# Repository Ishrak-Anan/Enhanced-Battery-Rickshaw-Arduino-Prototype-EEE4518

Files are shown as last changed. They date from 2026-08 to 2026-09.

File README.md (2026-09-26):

# Enhanced Battery Rickshaw Arduino Prototype — EEE 4518

An Arduino-based hardware prototype developed to explore practical **safety and energy-efficiency enhancements for battery-powered rickshaws**. The system integrates manual PWM motor control, ultrasonic obstacle detection with automatic stopping, LCD feedback, dual DC-motor control, and solar-assisted auxiliary functionality.

**Course:** EEE 4518  
**Project Type:** Open-ended Real-Life Engineering Problem  
**Team:** Team MurubbEEE

---

## Overview

Battery-powered rickshaws are widely used for short-distance transportation in Bangladesh. However, conventional battery rickshaws often have limited safety features, basic driver feedback, and high dependence on externally charged batteries.

This project explored several engineering modifications through a **physical hardware prototype** controlled by an Arduino.

The final prototype incorporated:

- Arduino-based control
- Driver-controlled PWM motor speed
- Dual DC-motor operation
- Ultrasonic obstacle detection
- Automatic motor stopping
- LCD information display
- Solar-panel integration
- Auxiliary lighting
- Hardware-level implementation and testing

---

## Problem Statement

The project was motivated by several issues associated with conventional battery-powered rickshaws:

- Uncontrolled or excessive speed
- Risk of collision
- Limited safety systems
- High electricity consumption
- Lack of driver information systems
- Limited use of renewable energy sources

The objective was to demonstrate how embedded electronics, sensors, motor control, and renewable-energy concepts could be integrated into a prototype platform.

---

## My Contribution

This project was developed collaboratively as part of our **EEE 4518 — Electrical and Electronic Workshop** coursework at the Islamic University of Technology (IUT).

My contributions included:

- **Component Research & Selection** — Researched and helped identify the components required for the proposed battery-rickshaw enhancement system.
- **Component Procurement** — Participated in sourcing and purchasing the finalized hardware components for the prototype.
- **Hardware Implementation** — Contributed directly to the physical implementation of the prototype, particularly **wiring and soldering**.
- **Hardware Debugging & Troubleshooting** — Worked on identifying and resolving hardware-related issues during prototype development and testing.
- **Presentation Development** — Prepared the complete project presentation, with support from a teammate.

The project was a collaborative team effort, and the original repository is maintained by
[Ar-Rafi-Ishraq](https://github.com/Ar-Rafi-Ishraq/Enhanced-Battery-Rickshaw-Arduino-Prototype-EEE4518).

## Hardware Prototype

<p align="center">
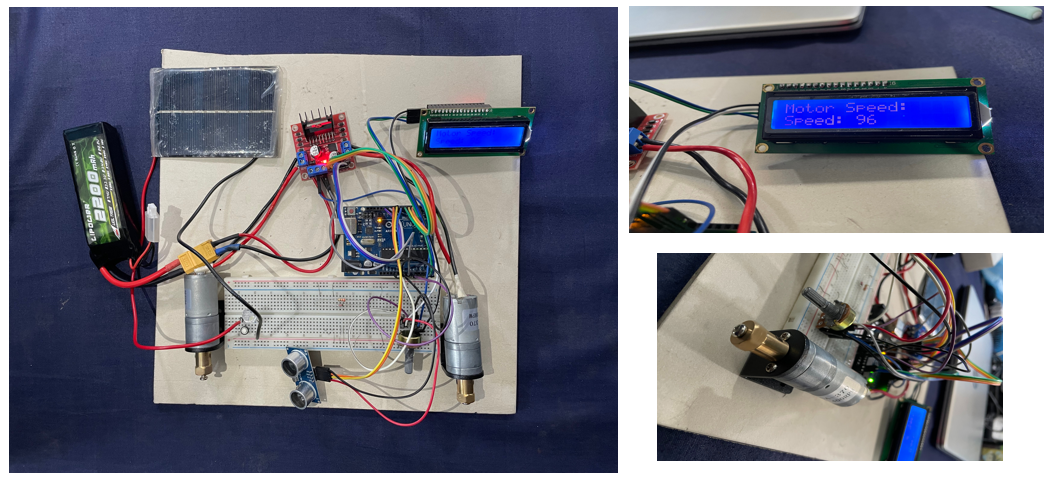
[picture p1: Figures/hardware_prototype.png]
Enhanced Battery Rickshaw Hardware Prototype
  
</p>

The physical prototype integrates the Arduino controller, motor driver, two DC motors, ultrasonic sensor, LCD, potentiometer-based driver input, solar panel, and supporting electronics.

---

## Circuit Schematic

The circuit schematic was designed using **Fritzing**.

<p align="center">
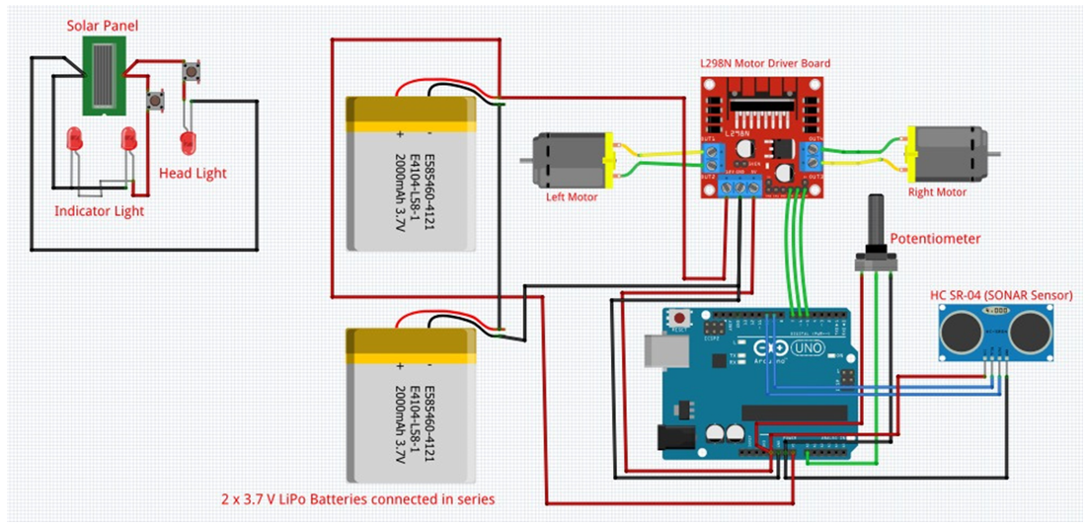
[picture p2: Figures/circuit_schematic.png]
Fritzing Circuit Schematic
  
</p>

The editable Fritzing project is available here:

[`Fritzing/l298n-arduino.fzz`](Fritzing/l298n-arduino.fzz)

---

# Implemented Features

## 1. Manual Motor Speed Control

A potentiometer connected to Arduino analog input `A0` acts as the driver's motor-speed command.

The Arduino reads the analog input and converts it into a PWM command for the L298N motor driver.

The PWM output is limited to:

```text
0 – 178
```

rather than the complete Arduino 8-bit PWM range of `0 – 255`.

Both DC motors receive the corresponding PWM command through the L298N motor driver.

> **Note:** The displayed speed value represents the motor PWM command, not an actual vehicle-speed measurement in km/h.

---

## 2. Obstacle Detection

An **HC-SR04 ultrasonic sensor** is mounted at the front of the prototype to measure the distance to nearby obstacles.

The Arduino continuously calculates the distance using the ultrasonic sensor.

The implemented safety threshold is:

```text
20 cm
```

If an obstacle is detected within approximately 20 cm, the system automatically stops both motors.

---

## 3. Automatic Motor Stopping

The motor-control logic follows:

```text
If distance < 20 cm:
    Stop both motors

Otherwise:
    Run motors according to potentiometer input
```

This provides a basic collision-avoidance mechanism for the prototype.

---

## 4. LCD Information Display

A **16×2 LCD with an I2C adapter** is used to provide information to the driver.

The display shows the motor-speed command generated from the potentiometer input.

I2C communication reduces the number of Arduino pins required for the LCD.

---

## 5. Dual-Motor Drive

Two DC geared motors are driven through an **L298N dual H-bridge motor driver**.

The Arduino controls:

- Motor direction
- Motor enable signals
- PWM speed command

Both motors are configured to move the prototype forward during normal operation.

---

## 6. Solar Integration

A small solar panel was incorporated into the prototype as part of the proposed renewable-energy enhancement.

The prototype demonstrates the concept of using solar energy for auxiliary electrical loads.

It does **not** implement a complete solar battery-charging system or maximum-power-point-tracking controller.

---

# System Control Flow

<p align="center">
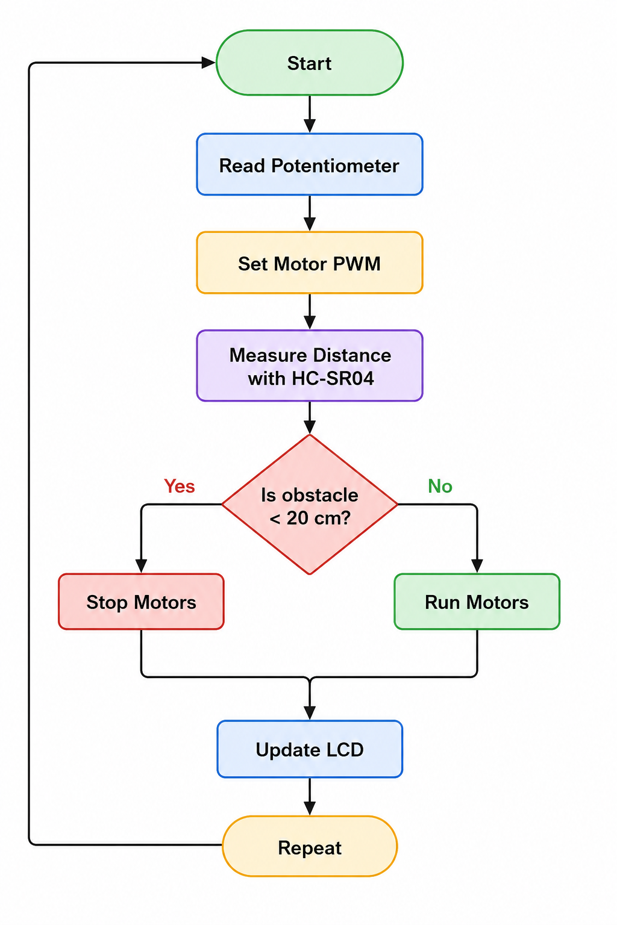
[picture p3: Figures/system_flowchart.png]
Arduino Control System Flowchart
  
</p>

The Arduino control process can be summarized as:

```text
Start
  ↓
Read Potentiometer
  ↓
Set Motor PWM
  ↓
Measure Distance with HC-SR04
  ↓
Is obstacle < 20 cm?
  ├── Yes → Stop Motors
  └── No  → Run Motors
  ↓
Update LCD
  ↓
Repeat
```

---

# Arduino Pin Connections

| Component | Signal | Arduino Pin |
|---|---|---:|
| HC-SR04 | Trigger | 9 |
| HC-SR04 | Echo | 10 |
| L298N Motor A | ENA / PWM | 5 |
| L298N Motor A | IN1 | 6 |
| L298N Motor A | IN2 | 7 |
| L298N Motor B | ENB / PWM | 11 |
| L298N Motor B | IN3 | 8 |
| L298N Motor B | IN4 | 12 |
| Potentiometer | Wiper | A0 |
| I2C LCD | SDA | A4 |
| I2C LCD | SCL | A5 |

A **common ground** is required between the Arduino, L298N, sensors, display, and motor power supply.

Detailed wiring information is available here:

[`Docs/Pin_Connections.docx`](Docs/Pin_Connections.docx)

---

# Arduino Firmware

The main Arduino source code is available at:

[`Arduino/TotalProjectCodeRickshaw.ino`](Arduino/TotalProjectCodeRickshaw.ino)

The firmware performs:

- Analog potentiometer reading
- PWM motor-speed command generation
- Dual-motor control
- Motor-direction control
- HC-SR04 distance measurement
- Obstacle detection
- Automatic motor stopping
- LCD updates
- I2C communication

---

## Required Arduino Libraries

The firmware uses:

```cpp
#include <Wire.h>
#include <LiquidCrystal_I2C.h>
```

`Wire` is included with the Arduino platform.

A compatible **LiquidCrystal_I2C** library must be installed before compiling the project.

---

# How to Run

## 1. Hardware Setup

Connect the components according to:

```text
Docs/Pin_Connections.docx
```

Important connections include:

```text
HC-SR04:
Trig → Pin 9
Echo → Pin 10

Motor A:
ENA → Pin 5
IN1 → Pin 6
IN2 → Pin 7

Motor B:
ENB → Pin 11
IN3 → Pin 8
IN4 → Pin 12

Potentiometer:
Wiper → A0

LCD:
SDA → A4
SCL → A5
```

---

## 2. Upload the Firmware

1. Open **Arduino IDE**.
2. Open:

```text
Arduino/TotalProjectCodeRickshaw.ino
```

3. Install a compatible `LiquidCrystal_I2C` library if necessary.
4. Select the correct Arduino board.
5. Select the correct serial port.
6. Compile the program.
7. Upload it to the Arduino.

---

## 3. Test the System

Rotate the potentiometer to change the motor-speed command.

Move an object in front of the HC-SR04 sensor.

When the measured distance becomes less than approximately:

```text
20 cm
```

both motors should automatically stop.

Remove the obstacle and the motors should resume operation according to the potentiometer input.

---

# Main Hardware Components

The prototype uses the following major components:

| Component | Quantity |
|---|---:|
| Arduino Uno | 1 |
| L298N Dual H-Bridge Motor Driver | 1 |
| HC-SR04 Ultrasonic Sensor | 1 |
| DC Gear Motors | 2 |
| 16×2 LCD | 1 |
| I2C LCD Adapter | 1 |
| Potentiometer | 2 |
| Solar Panel | 1 |
| LiPo Battery / Power Supply | 1 |
| LED / Auxiliary Lighting | 1 |
| Jumper Wires and Connecting Hardware | As required |

The initial component estimate created during project planning is preserved in:

[`Archive/initial_component_budget.txt`](Archive/initial_component_budget.txt)

---

# Project Documentation

The project documentation is available in the [`Docs`](Docs/) directory.

## Final Project Report

[`EEE4518_Final_Project_Report.pdf`](Docs/EEE4518_Final_Project_Report.pdf)

The report documents the completed project, including:

- Problem identification
- Project objectives
- Component selection
- Circuit design
- Working principle
- Arduino implementation
- Hardware implementation
- Problems encountered
- Final prototype
- Conclusion
- References

---

## Project Proposal

[`EEE4518_Project_Proposal.pdf`](Docs/EEE4518_Project_Proposal.pdf)

The original proposal contains the initial project concept and the broader set of enhancements considered during the planning stage.

---

## Pin Connections

Detailed wiring and Arduino pin assignments are available in:

[`Docs/Pin_Connections.docx`](Docs/Pin_Connections.docx)

---

## Progress Updates

Intermediate development documentation is available in:

[`Docs/Progress_Updates/`](Docs/Progress_Updates/)

---

# Presentation

The final project presentation is available in the [`Presentation`](Presentation/) directory.

Files:

- [`Team-MurubbEEE-Final-Presentation.pdf`](Presentation/Team-MurubbEEE-Final-Presentation.pdf)
- [`Team-MurubbEEE-Final-Presentation.pptx`](Presentation/Team-MurubbEEE-Final-Presentation.pptx)

---

# Repository Structure

```text
Enhanced-Battery-Rickshaw-Arduino-Prototype-EEE4518/
│
├── README.md
│
├── Archive/
│   └── initial_component_budget.txt
│
├── Arduino/
│   └── TotalProjectCodeRickshaw.ino
│
├── Docs/
│   ├── Progress_Updates/
│   ├── EEE4518_Final_Project_Report.pdf
│   ├── EEE4518_Project_Proposal.pdf
│   └── Pin_Connections.docx
│
├── Figures/
│   ├── circuit_schematic.png
│   ├── hardware_prototype.png
│   └── system_flowchart.png
│
├── Fritzing/
│   └── l298n-arduino.fzz
│
└── Presentation/
    ├── Team-MurubbEEE-Final-Presentation.pdf
    └── Team-MurubbEEE-Final-Presentation.pptx
```

---

# Project Evolution

The original proposal considered several possible enhancements, including:

- Speed sensing
- Automatic response to overspeeding
- Obstacle detection
- Solar integration
- Reverse/recovery charging
- Lighting
- Driver information display

Not every proposed feature was implemented in the final prototype.

The completed hardware prototype focused on:

- Potentiometer-based motor-speed command
- PWM motor control
- HC-SR04 obstacle detection
- Automatic stopping
- LCD feedback
- Dual-motor control
- Solar-assisted auxiliary integration

Separating the **proposed features** from the **implemented features** provides a more accurate representation of the completed engineering work.

---

# Current Limitations

This prototype was developed as an educational proof of concept and has several limitations:

- No wheel encoder or Hall-effect sensor for actual vehicle-speed measurement
- No calibrated speed measurement in km/h
- LCD displays the PWM control command rather than actual vehicle speed
- No battery state-of-charge monitoring
- No regenerative braking implementation
- No reverse-charging implementation
- No closed-loop motor-speed control
- No production-grade braking actuator
- No complete solar charge controller
- Fixed prototype-scale obstacle threshold
- L298N motor driver is appropriate for the prototype but not for a full-scale rickshaw traction motor

Therefore, this project should be considered a **prototype demonstration**, not a road-ready vehicle control system.

---

# Possible Future Improvements

Future versions of the system could include:

- Wheel-speed sensing using a Hall sensor or encoder
- Calibrated speed measurement in km/h
- Closed-loop speed control
- Speed-dependent stopping distance
- Battery voltage and current monitoring
- Battery state-of-charge estimation
- Dedicated solar charge controller
- Higher-efficiency motor controller
- Regenerative braking
- Indicator and headlight automation
- Data logging
- Wireless telemetry
- Full-scale braking-system integration
- Vehicle-level safety testing

---

# Team

This project was developed by **Team MurubbEEE**:

- Ar-Rafi Ishraq
- Ishrak Anan
- Taufeeq Hassan Omio
- Ashfiq Ul Rahman
- Tahsik Islam Sampad
- Bayzid Mohammed Sakib

---

# Tools and Technologies

- Arduino Uno
- Arduino IDE
- Embedded C/C++
- Fritzing
- Tinkercad during development
- HC-SR04 ultrasonic sensing
- L298N H-bridge motor driver
- PWM motor control
- I2C communication
- 16×2 LCD
- DC motor control
- Hardware prototyping
- Soldering and circuit assembly

---

# Academic Context

This project was completed as an **open-ended engineering project for EEE 4518**.

The objective was to identify a real-world problem and use engineering knowledge to design and implement a practical solution.

The selected problem was the enhancement of battery-powered rickshaws through embedded control, safety sensing, driver feedback, and renewable-energy concepts.

---

# Repository Maintainer

**Ar-Rafi Ishraq**  
Electrical and Electronic Engineering

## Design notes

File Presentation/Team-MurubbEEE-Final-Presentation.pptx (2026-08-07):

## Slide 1

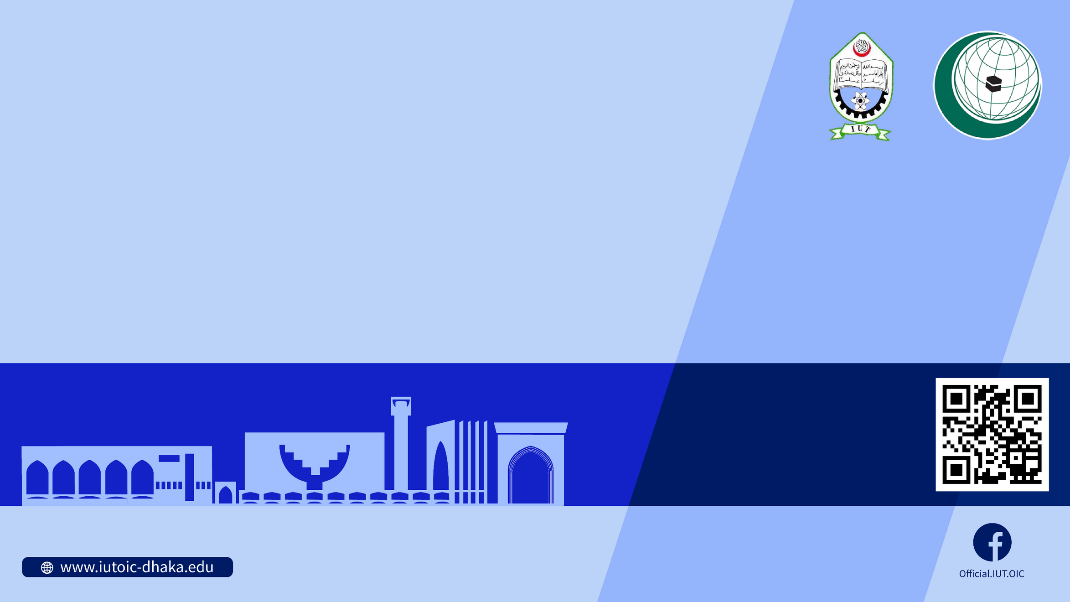
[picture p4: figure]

FINAL PROJECT DEMONESTRATION

EEE 4518: ELECTRICAL AND ELECTRONIC WORKSHOP

PROJECT TITLE: ENHANCEMENT OF BATTERY-POWERED RICKSHAW

Submitted by – Team Murubb_EEE

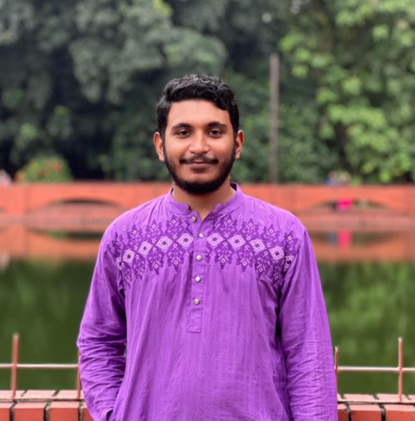
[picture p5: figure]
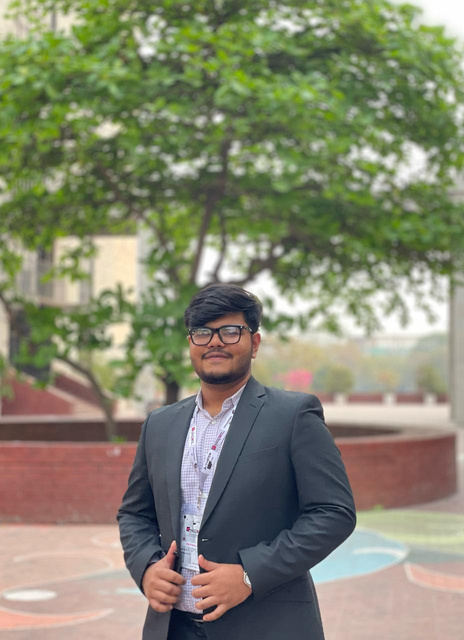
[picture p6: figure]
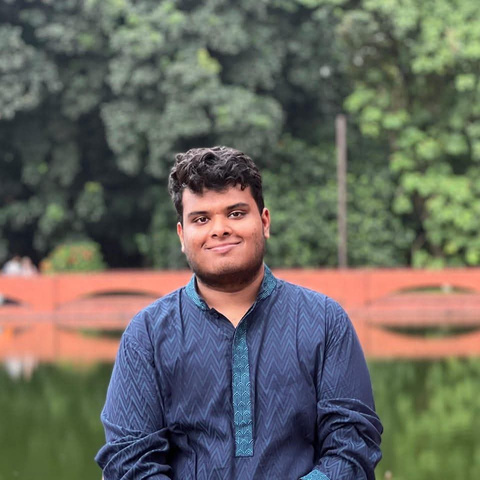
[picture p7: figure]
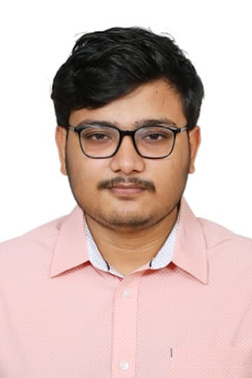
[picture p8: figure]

AR RAFI ISHRAQ
210021330

ISHRAK ANAN
210021212

TAUFEEQ HASSAN OMIO
210021214

ASHFIQ UL RAHMAN
210021342

TAHSIK ISLAM SAMPAD
210021318

BAYZID MOHAMMED SAKIB
210021250

Creating Global Citizens Rooted with Islamic Values

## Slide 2

OUTLINE

  1. ABSTRACT
  2. PROBLEM STATEMENTS AND PROPOSED SOLUTIONS
  3. DESIGN
  4. IMPLEMENTATION
  5. ANALYSIS AND EVOLUTION
  6. REFLECTION OF INDIVIDUAL AND TEAMWORK
  7. REFERENCES

3

2

Creating Global Citizens Rooted with Islamic Values

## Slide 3

We, team Murubbeee, aim to work on enhancing battery-run rickshaws in Bangladesh. Battery rickshaws have become a common urban transportation in Bangladesh, especially in busy cities like Dhaka, and Chittagong. According to Dhaka Tribune’s report on May 24, 2024, almost 60 lakh battery rickshaws are operating on the streets of Bangladesh. These rickshaws provide us with the benefits of fast transportation as compared to their counterpart, human-powered rickshaws. However, these benefits come with a price. Battery rickshaws are the major reasons for accidents, excessive electricity usage, and traffic-related issues. To address these issues and also upgrade these battery-run rickshaws for more efficient results, we propose our newly modified battery rickshaws.

ABSTRACT

3

3

Creating Global Citizens Rooted with Islamic Values

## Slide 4

PROBLEM STATEMENTS

1. Unnecessary speeding of battery rickshaws.
2. Collisions that lead to minor or severe injuries and life threats
3. Excessive use of electricity for charging the battery-run rickshaws
4. Lack of safety measurements in the rickshaws
5. Absence of an information system in the rickshaw.

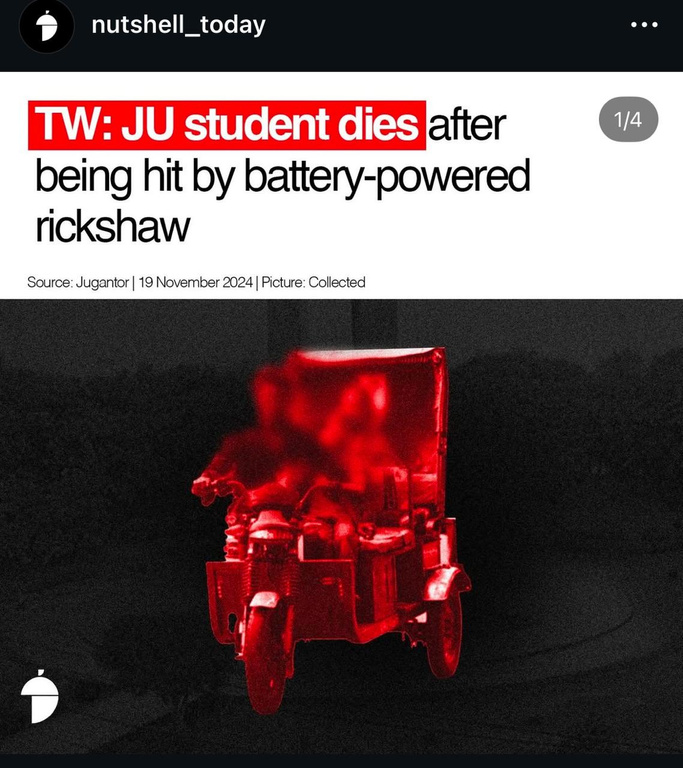
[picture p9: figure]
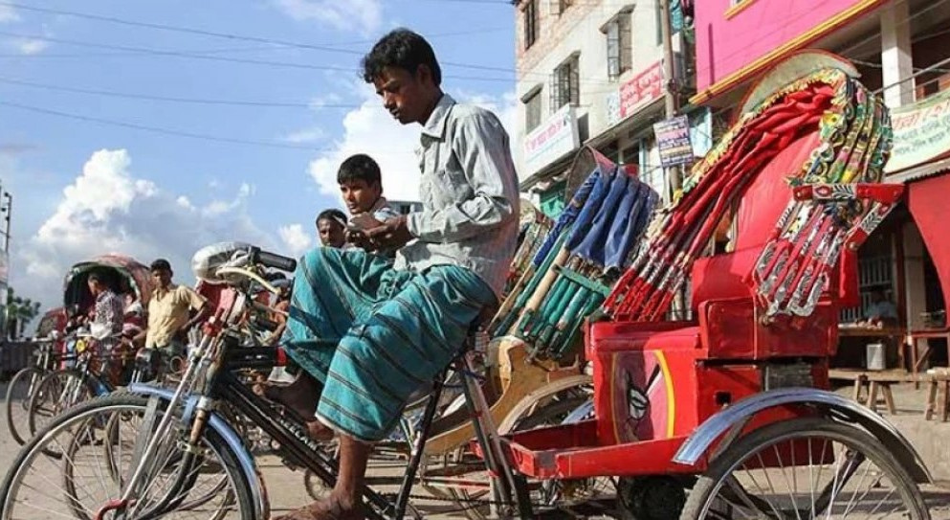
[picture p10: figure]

Creating Global Citizens Rooted with Islamic Values

4

4

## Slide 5

PROPOSED SOLUTIONS

  1. Solar panel installation on the top of rickshaw hoods
  2. Speed sensors to detect the speed of the rickshaw
  3. Obstacle detector to be installed at the front portion
  4. A system that can respond to overspeed and reduce chances of collisions by controlling the power supply to motor.
  5. Addition of indicator lamps and headlamps
  6. Information system (LED display) to show necessary data (speed, charge, etc.)

5

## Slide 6

3.1 DESIGN: METHODS

Components Used in the prototype:
  - ARDUINO
  - 400 RPM motors
  - Dual Motor Drivers
  - Solar Panel
  - Speed Measuring Module
  - LCD Panels
  - SONAR sensor
  - LED indicators

Microcontroller Used: ATmega328

Code implemented by: Arduino IDE

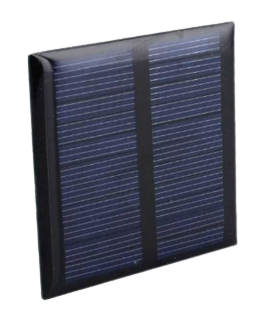
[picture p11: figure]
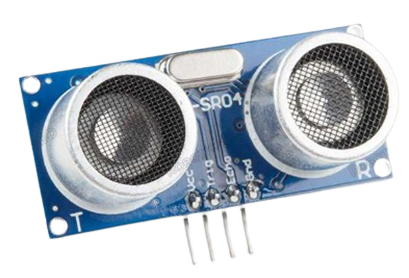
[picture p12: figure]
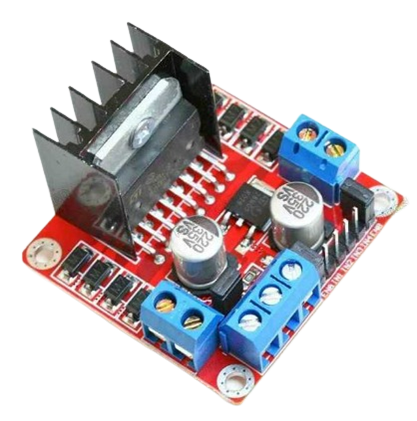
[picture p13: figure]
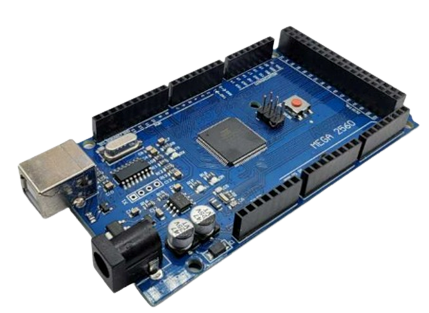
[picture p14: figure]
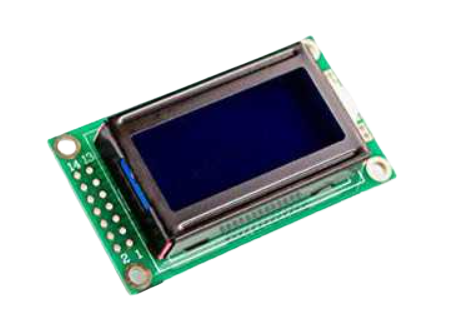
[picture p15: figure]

5

6

Creating Global Citizens Rooted with Islamic Values

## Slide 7

3.2 DESIGN: CIRCUIT DIAGRAM

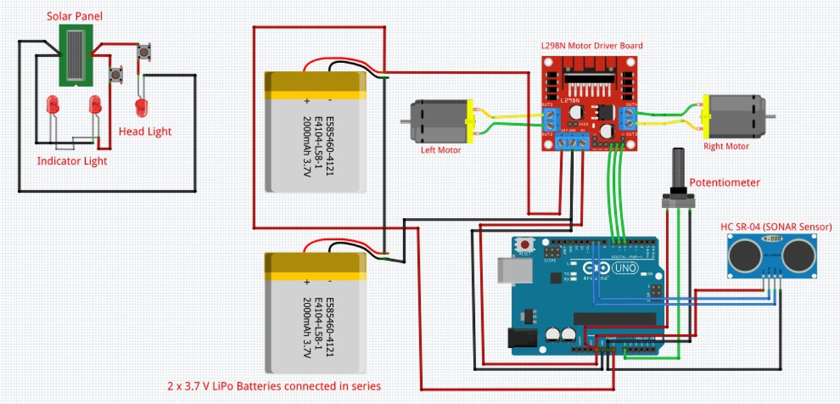
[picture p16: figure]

Creating Global Citizens Rooted with Islamic Values

5

7

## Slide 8

3.3 DESIGN: SIMULATION

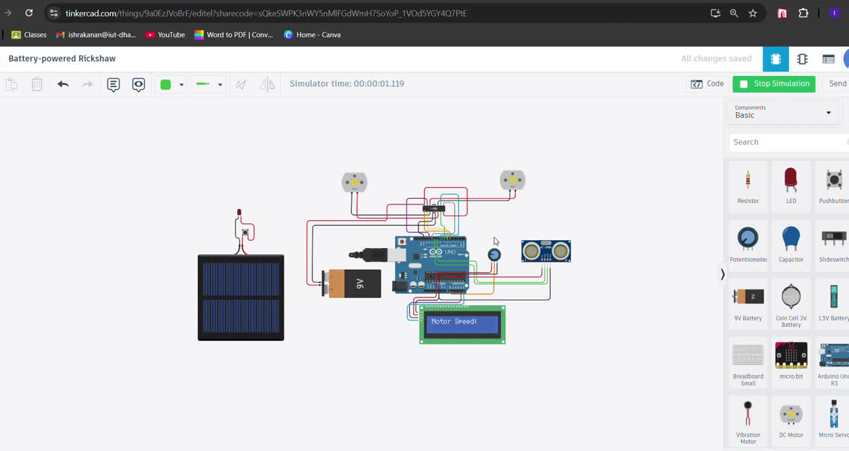
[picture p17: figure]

Creating Global Citizens Rooted with Islamic Values

5

8

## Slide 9

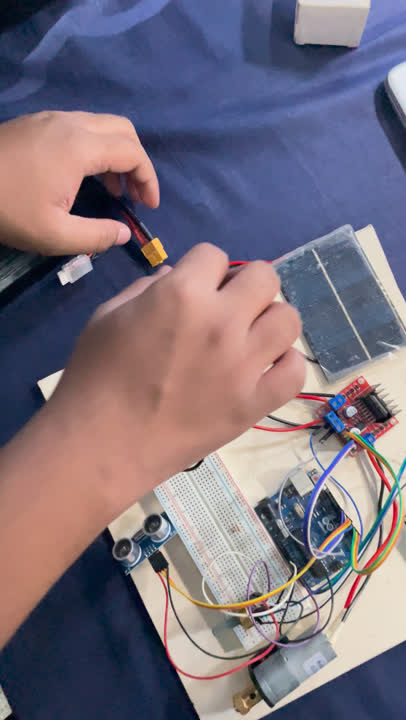
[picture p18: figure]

Creating Global Citizens Rooted with Islamic Values

4. IMPLEMENTATION:
DEMONSTRATION

5

9

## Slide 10

4.1 IMPLEMENTATION: PHOTO GALLERY

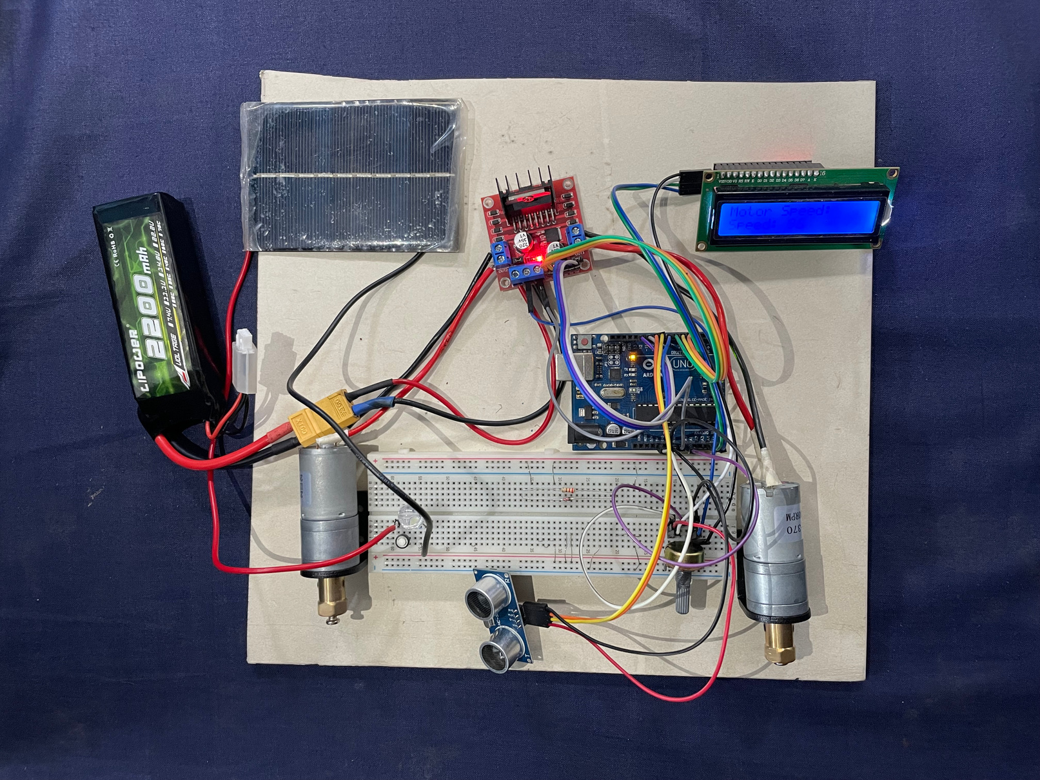
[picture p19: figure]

Creating Global Citizens Rooted with Islamic Values

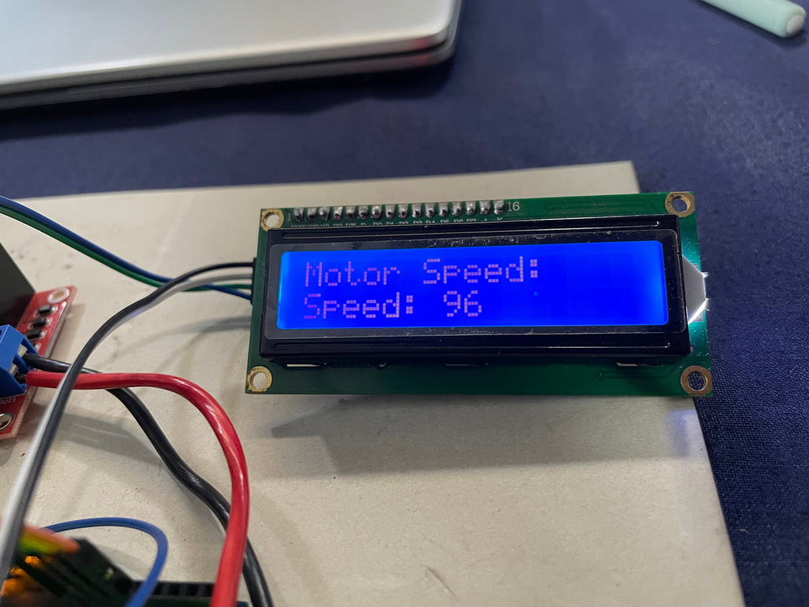
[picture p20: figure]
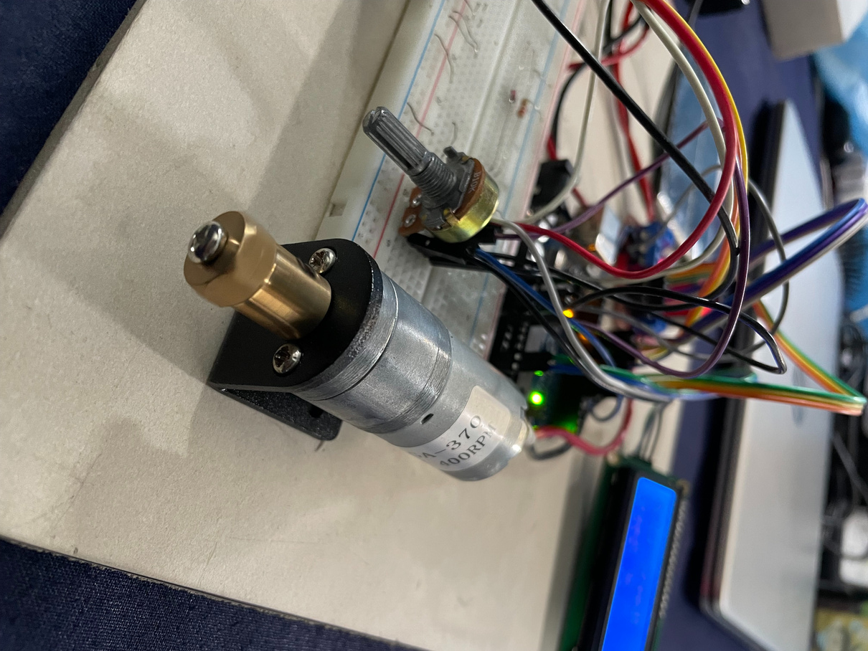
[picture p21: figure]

5

10

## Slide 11

4.2 IMPLEMENTATION:
EXTERNAL LINKS

https://youtube.com/shorts/Rr9jDDKW8tM?si=Zxs3Y1whMCS7SmcW

https://drive.google.com/file/d/10qWkcPVF2pdNtCMIhrEbjjUucbQbvRDR/view?usp=drive_link

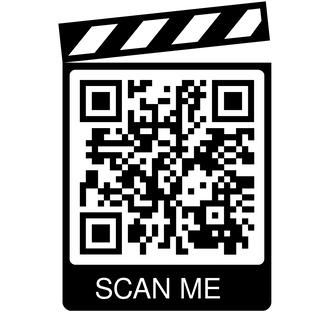
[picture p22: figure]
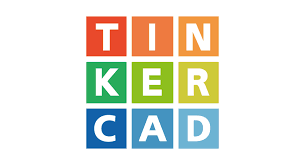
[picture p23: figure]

https://youtu.be/czvA3kF8Too

5

11

Creating Global Citizens Rooted with Islamic Values

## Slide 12

5. ANALYSIS AND EVALUATION

5.1 Novelty
5.2 Project Management and Cost Analysis
5.3 Practical Considerations of the Design
5.4 Assessment of the Impact of the Project
5.5 Evaluation of the Sustainability

5

12

Creating Global Citizens Rooted with Islamic Values

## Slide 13

Our project introduces several innovative enhancements to existing battery-run rickshaws, aiming to improve safety, efficiency, and sustainability.

5.1 NOVELTY

INTELLIGENT SPEED CONTROL SYSTEM

UNIQUENESS

OBSTACLE DETECTION

ENHANCED SAFETY FEATURES

ENERGY SAVING FEATURES

DATA-DRIVEN MONITORING SYSTEM

5

13

Creating Global Citizens Rooted with Islamic Values

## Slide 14

5.2 PROJECT MANAGEMENT & COST ANALYSIS

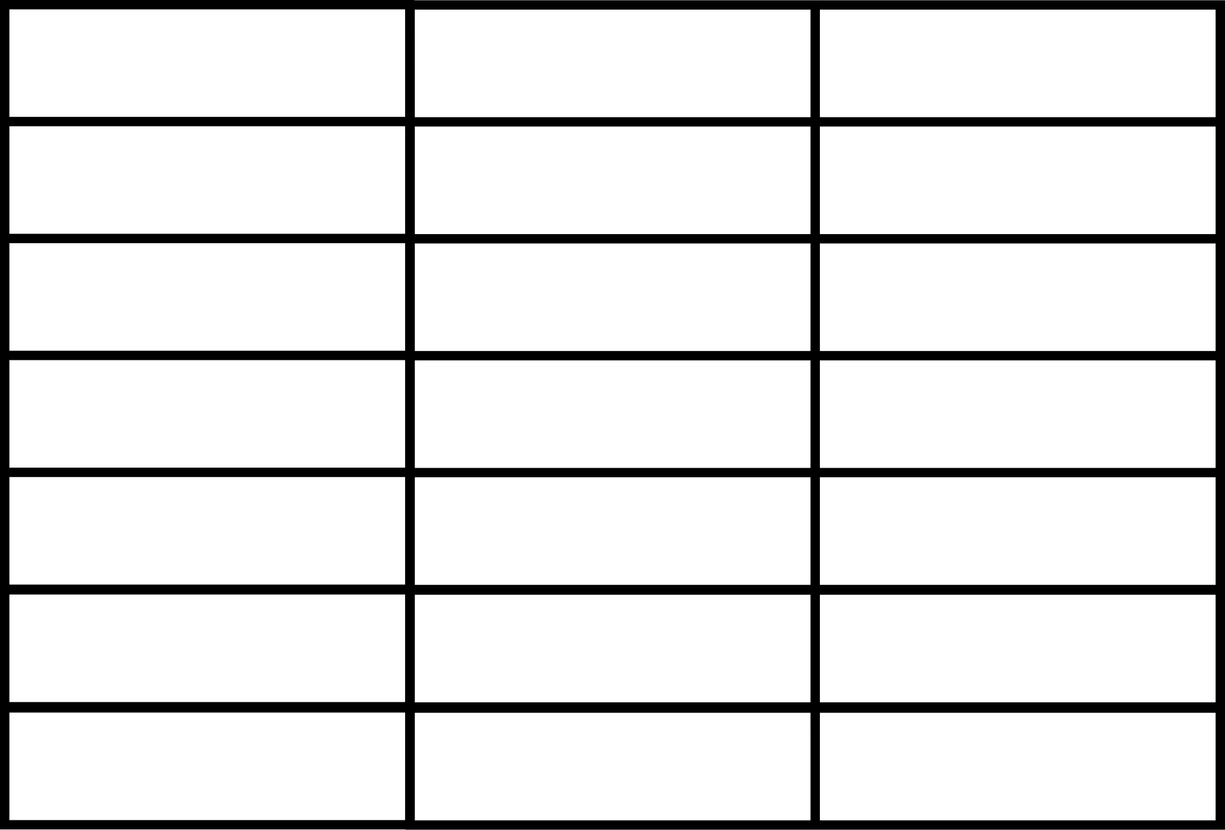
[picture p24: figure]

Component Name

Arduino UNO (R3)

Quantity

Price

Component Name

Quantity

Price

1

995/-

Solar Panel
(RYO 474)

LED Indicators

Display

1

160/-

Motor Driver
(L298N)

1

120/-

30/-

1

1

10/-

90/-

SONAR sensor (HC SR-04)

Potentiometer (10K)

2

1

60/-

Adapter Module

Jumper wire + Hexa connector

Soldering Kit

1

90/-

LiPo Battery 11V

1

1600/-

1 set

260/-

Motor
(25GA 370 400 RPM)

2

800/-

1 Set

400/-

5

14

Creating Global Citizens Rooted with Islamic Values

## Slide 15

5.3 PRACTICAL CONSIDERATIONS

PRACTICAL CONSIDERATIONS

Public Health & Safety

Environment

Cultural & Societal Needs

  - Collision Detection ensures passenger safety
  - Speed control system ensures safe journey
  - Enhanced safety measures like indicators ensure safety on roads

  - Energy saving features like Solar Panel
  - Reduces charging time, saving excess use of electricity and fossil fuels
  - Zero carbon emission

  - Rickshaw represents the cultural tradition in Bangladesh
  - Source of income for low-income people
  - Easier mode of communication for people earning less.

5

15

Creating Global Citizens Rooted with Islamic Values

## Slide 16

5.4 ASSESSMENT OF THE IMPACT

SOCIETAL ISSUES

  - Reducing Accidents
  - Lowering electricity demands
  - Enhancing Public Perception

IMPACT
ASSESSMENT

HEALTH & SAFETY ISSUES

  - Reducing the risk of high-speed collisions
  - Prevents accidents involving pedestrians, other vehicles and roadside structures
  - Improces visibility at night and in adverse weather conditions

LEGAL ISSUES

  - Unauthorized road usage
  - Illegal electricity connections
  - Lack of standasrdization

CULTURAL ISSUES

  - Preserving the role of rickshaws in urban transport
  - Improving public image of rickshaws
  - Supporting rickshaw pullers and owners

5

16

Creating Global Citizens Rooted with Islamic Values

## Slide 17

5.5 EVALUATION OF THE SUSTAINABILITY

Sustainability

  - Enhanced Safety
  - Job security and opportunities
  - Improved Public Perception
  - Inclusion and accessibility
  - Reduction in traffic incidents

Societal Context

  - Reduction in carbon footprint
  - Decreased electronic waste
  - Lower energy wastage
  - Noise pollution reduction
  - Sustainable urban mobility

5

Environmental
Context

  - Energy Efficiency
  - Reduction in electricity Demand
  - Long-term economic viability
  - Durability and maintenance
  - Environmental footprint

Creating Global Citizens Rooted with Islamic Values

17

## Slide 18

6. REFELCTION ON INDIVIDUAL AND TEAMWORK

6.1 Individual Contribution of Each Team Member
6.2 Mode of Teamwork
6.3 Diversity Statement of Team
6.4 Assessment of the Impact of the Project

Creating Global Citizens Rooted with Islamic Values

5

18

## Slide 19

6.1 INDIVIDUAL CONTRIBUTION OF EACH TEAM MEMBER

AR-RAFI ISHRAQ

  - Research on component selection
  - Purchasing components
  - Hardware implementation (wiring, soldering)
  - Code for individual Module
  - Debugging

ASHFIQ UL RAHMAN

  - Research on component selection
  - Purchasing components
  - Research on project feasibility and impact
  - Hardware implementation (wiring, soldering)
  - Report writing
  - Debugging

ISHRAK ANAN

  - Research on component selection
  - Purchasing components
  - Hardware implementation (wiring, soldering)
  - Debugging
  - Preparing presentation

TAHSIK ISLAM SAMPAD

  - Purchasing components
  - Budget designing
  - Research on project feasibility and impact
  - Hardware implementation (wiring, soldering)

TAUFEEQ HASSAN OMIO

  - Research on component selection
  - Research on project feasibility and impact
  - Hardware implementation (wiring, soldering)
  - Report writing
  - Preparing presentation

BAYZID MOHAMMED SAKIB

  - Purchasing components
  - Budget designing
  - Hardware implementation (wiring, soldering)
  - Documentation

5

19

Creating Global Citizens Rooted with Islamic Values

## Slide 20

6.2 MODE OF TEAMWORK

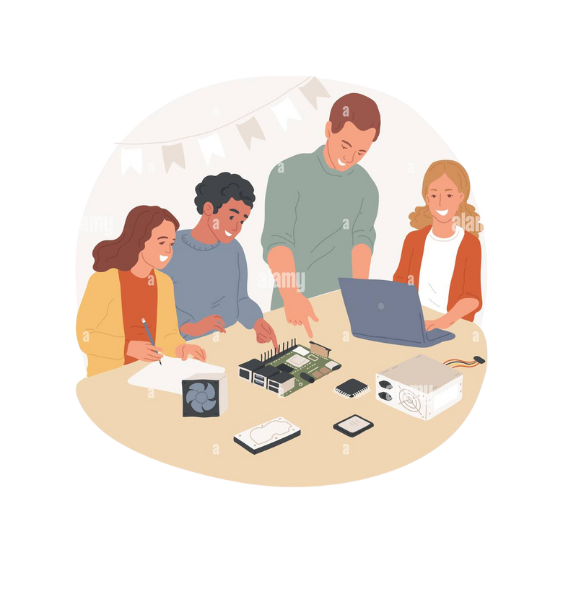
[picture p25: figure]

PROTOTYPING AND TESTING

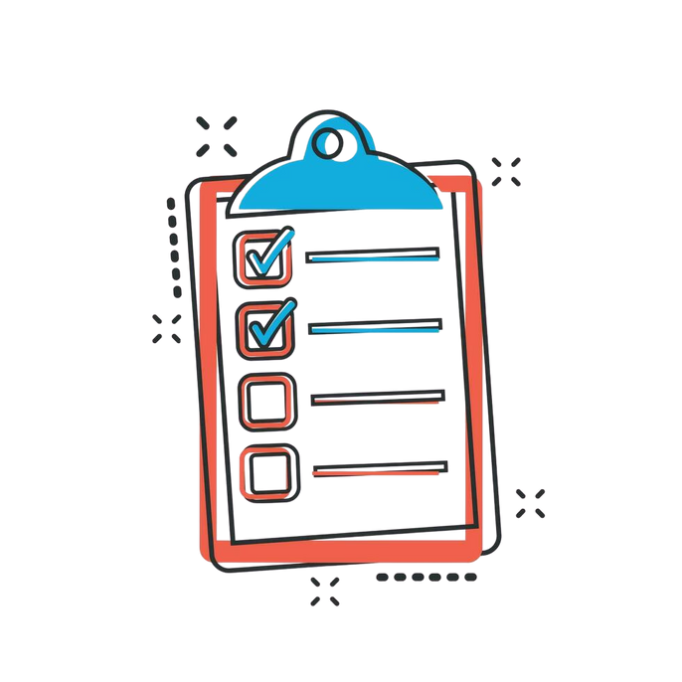
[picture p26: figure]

ROLE BASED TASK ALLOCATION

BRAINSTORMING AND GROUP DISCUSSIONS

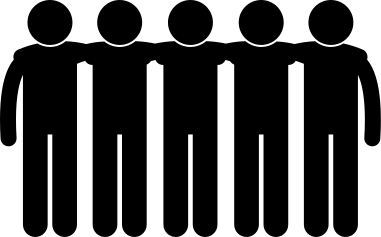
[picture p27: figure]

TEAM COLLABORATION

5

20

Creating Global Citizens Rooted with Islamic Values

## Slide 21

6.3 DIVERSITY STATEMENT OF TEAM

  - ROLE BASED TASK ALLOCATION
  - INCLUSIVE AND COLLABORATIVE ENVIRONMENT
  - ADAPTIBILTY AND LEARNING
  - COMMITMENT TO ENVIRONMENTAL AND SOCIAL IMPACT

5

21

Creating Global Citizens Rooted with Islamic Values

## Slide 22

Q2

Q4

Q6

Q1

COMPONENT SELECTION AND PROCUREMENT

Q3

CODING AND DEBUGGING

Q5

PRESENTATION

IDEATION AND RESEARCH

HARWARE IMPLEMENTATION

DOCUMENTATION

6.4 LOG BOOK OF PROJECT IMPLEMENTATION

5

22

Creating Global Citizens Rooted with Islamic Values

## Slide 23

THANK YOU

5

23

Creating Global Citizens Rooted with Islamic Values

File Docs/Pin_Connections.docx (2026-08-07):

1. HC-SR04 Ultrasonic Sensor

- Trig Pin: Connect to Arduino digital pin 9.
- Echo Pin: Connect to Arduino digital pin 10.
- VCC: Connect to Arduino 5V.
- GND: Connect to Arduino GND.

2. L298N Motor Driver

- Motor A (Left Motor):
  - ENA (Enable A): Connect to Arduino PWM pin 5 for speed control.
  - IN1: Connect to Arduino digital pin 6.
  - IN2: Connect to Arduino digital pin 7.
  - Motor Output Terminals:
    - OUT1: Connect to the positive terminal of the first motor.
    - OUT2: Connect to the negative terminal of the first motor.
- Motor B (Right Motor):
  - ENB (Enable B): Connect to Arduino PWM pin 11 for speed control.
  - IN3: Connect to Arduino digital pin 8.
  - IN4: Connect to Arduino digital pin 12.
  - Motor Output Terminals:
    - OUT3: Connect to the positive terminal of the second motor.
    - OUT4: Connect to the negative terminal of the second motor.
- 12V Motor Power Supply:
  - Connect the positive terminal of a 12V power supply to the +12V terminal on the L298N.
  - Connect the negative terminal of the 12V power supply to the GND terminal on the L298N.
- Ground Connection: Connect the GND on the L298N to the GND of the Arduino to ensure a common ground.

3. Potentiometer (For Manual Speed Control)

- Middle Pin (Wiper): Connect to Arduino analog pin A0.
- One Side Pin: Connect to Arduino 5V.
- Other Side Pin: Connect to Arduino GND.

4. 16x2 I2C LCD Display

- SDA (Serial Data): Connect to Arduino A4.
- SCL (Serial Clock): Connect to Arduino A5.
- VCC: Connect to Arduino 5V.
- GND: Connect to Arduino GND.

5. Arduino Power Supply

- VIN Pin: If you're using the 12V motor power supply for the entire system, connect the 12V power supply positive terminal to the Arduino’s VIN pin.
- GND: Connect the GND of the Arduino to the shared ground with the L298N and the 12V power supply.

Summary of Pin Connections to Arduino

- HC-SR04 Sensor: Trig (Pin 9), Echo (Pin 10)
- Motor A: ENA (Pin 5), IN1 (Pin 6), IN2 (Pin 7)
- Motor B: ENB (Pin 11), IN3 (Pin 8), IN4 (Pin 12)
- Potentiometer: Middle pin (A0)
- I2C LCD: SDA (A4), SCL (A5)

Power Supply Notes

- Use the 12V power supply to power the motors via the L298N.
- The same 12V power supply can power the Arduino through the VIN pin, and the Arduino will regulate it to 5V for its internal components.

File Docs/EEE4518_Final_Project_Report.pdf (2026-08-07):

## ISLAMIC UNIVERSITY OF TECHNOLOGY (IUT)

GAZIPUR-1704, DHAKA, BANGLADESH

DEPARTMENT OF ELECTRICAL AND ELECTRONIC ENGINEERING

# EEE 4518

# ELECTRICAL AND ELECTRONIC WORKSHOP

# PROJECT TITLE: Enhancement of Battery-Powered

Rickshaw.

## SUBMITTED BY:

# Team Name:murubbEEE

## - Ar-rafi Ishraq 210021330 - Ishrak Anan 210021212 - Taufeeq Hassan Omio 210021214 - Ashfiq Ul Rahman 210021342 - Tahsik Islam Sampad 210021318 - Bayzid Muhammad Sakib 210021250

## DATE OF SUBMISSION: 05.03.2025

# PROJECT REPORT

Project name by team name

## Table of Contents

# 1.Introduction

- Problem Statement

-Battery-run rickshaws are the cause of a good number of problems in the urban areas of our country. The major issues that we will be addressing are:

1. Unnecessary speeding of battery rickshaws.
2. Collisions that lead to minor or severe injuries and life threats
3. Excessive use of electricity for charging the battery-run rickshaws
4. Lack of safety measurements in the rickshaws
5. Absence of an information system in the rickshaw.

Battery-run rickshaws are most criticized for their poor safety measurements and functionality. The major issue is that these rickshaws do not have any safety options to control overspeeding. The speeds these rickshaws can gain are often too hard to control with the brakes they are equipped with. These lead to collisions with other vehicles on the road and serious injuries, sometimes even death. The inclusion of speed sensors and automatic response systems for overspeeding can resolve this issue to an extent.
Another problem that the battery-run rickshaws create is the electricity they consume for charging. A study conducted in 2023 shows that the battery-run rickshaws consume up to 450 MW of electricity every day. However, this number might be even larger as there are many illegal connections used for charging these rickshaws. To address this issue, the use of renewable energy systems and the addition of a hybrid mechanism is proposed.
- Existing Solution

For this case , usually traditional battery rickshaws use illegal line to change their batteries. Normally in the accident prone areas , rickshaw-pullers manually sense the speed and obstacles as there is no established technologies to detect over speeding and obstacles .In our country , manual brakes are used when any chance of collision arises .Indicator lamps and headlamps are not used that much but in the modern rickshaws headlights are used now a days .Led display is used rarely in the modern rickshaws. But in the traditional rickshaws , there isn’t any technology available to show necessary information.

- Proposed Solution

-To solve the mentioned problem statements above, we aim to use several sensors and a hybrid mechanism in battery-run rickshaws accompanied by the use of renewable sources to cater to power saving. The proposed modifications are:

1. Solar panel installation on the top of rickshaw hoods
2. Speed sensors to detect the speed of the rickshaw
3. Obstacle detector to be installed at the front portion
4. A system that can respond to overspeed and reduce chances of collisions by controlling the power supply to motor.
5. Addition of indicator lamps and headlamps
6. Information system (LED display) to show necessary data (speed, charge, etc.)

The prototype we aim to make will comprise of the following modules:
- Arduino
- Solar panel
- Speed measuring module
- Ultrasonic SONAR sensor (HC-SR04)
- Dual Motor drivers
- LCD module
- LED
- An alternator

# 2.Objectives

Team murubbEEE intends to work on enhancing battery-run rickshaws in Bangladesh. Our aim is to ensure safety, increase the efficiency and sustainability of battery-run rickshaws . The proposed enhancement of the systems we want to go through is :
- Reducing reliance on grid electricity by incorporating solar panels.
- Ensuring safety by bringing in speed sensors, obstacle detector and automatic speed regulation system
- Installing functions like indicator lamps, headlamps and LED display for ensuring safety and enhancing data monitoring
- Utilizing Arduino-based automation, motor drivers for optimizing the control system and an LCD module for providing efficient operation and feedback.

# 3.Required Components

# 4.Circuit Diagram

Sl No. | Component Name | Value/Model | Quantity | Price (BDT)
1 | Aurduino – UNO | R3 | 1 | 995/-
2 | Motor Driver | L298N | 1 | 120/-
3 | Potentiometer | 10K | 2 | 30/-
4 | Sonar sensor | HC SR-04 | 1 | 60/-
5 | LiPo Battery | 11 V | 1 | 1600/-
6 | Motor | 25GA 370,12V gear | 2 | 800/-
7 | Solar Panel | RYO 474 | 1 | 160/-
8 | LED | | 1 | 10/-
9 | Display | LCD 16*2 Blue Backlight | 1 | 155/-
10 | Adapter Module | I2C LCD | 1 | 90/-
11 | Jumper Wires + HEXA | - | 1 set+2 | 100+160/-
12 | Soldering Kit | | 1 set | 400/-
Total | | | | 4680/-


## 4.1 Explanation:

The usage and significance of the components used in this project are discussed below:

- Aurduino UNO ; - It works as central controller device. It reads datas from sensors and adjust various functions. From speed sensor , it reads the command and thus adjusts motor speed . From sonar sensor’s input, it triggers an automatic braking response . Also aurduino balances the operations of solar panel , LED and other integrated devices .
- Motor Driver : – It controls motor’s speed and direction and further ensuring precise control . It also cntrols the power supply to the rickshaw by observing the speed and obstacle .
- Potentiometer :- It helps to regulate the speed of the rickshaw. Acting as a speed control device, it also adjusts voltage for motor control.
- Sonar Sensor: – It detects obstacles to prevent collisions. Measuring the distance between rickshaw and objects ,it sends alerts and triggers automatic braking if the object is likely to collide in a short time.
- Motor :- It acts as the primary propulsion system . It works by converting electrical energy into mechanical motion, thus optimizing efficiency.
- Solar panel: -It’s a device which converts sunlight into the electrical energy to charge the battery.It also reduces the dependency on power grid and also saves electricity costs .
- LED:- It ensures safety by making the rickshaw more noticeable . Actually LED is used as indicator or headlamps.
- LiPo Battery: – It provides power to the electronic components as well as to the rickshaw. At the same time, it also increases battery health and reduces charging time.
- Display: – It provides instant feedback to the driver by showing different real time data like speed , battery status and alerts .
- Adater Module: – It helps in efficient power distribution between the electronic components.
- Jumper wires , Hexa and Soldering Kits: – To connect the electronic components jumper wires were used .To fix the components with board Hexa and soldering kits were used .

# 5.Features

Team murubbEEE provides some indistinctive features for the enhancing performance of battery-run rickshaw model. The features are given below:

- Automatic Speed detection system (potentiometer)
- Obstacle detection system (sonar sensor)
- Energy saving system (solar panel)
- Digital data portraying system (LCD display)
- Enhancing safety measurements (LED )

# 6.Working Principle

The components used in the model have different functions in enhancing the performance. The ARDUINO UNO receives data from the sensors and works accordingly. Speed sensor is used to detect speed and potentiometer is used in controlling the speed. The SONAR sensor is used to detect objects and the automatic braking system serves in avoiding sudden collisions. LED headlamps and the indicator lamps turn on automatically when it is needed such as: low-light conditions and sudden turning/braking. The monitor used in the display system keeps the driver updated about the obstacle alerts, battery charge level and speed. The solar panel installed over the hoods capture sunlight and convert it into electrical energy. It reduces dependency on the external charging and reduces pressure on the electrical grid line.

## 6.1 Flowchart:


## 6.2 Explanation:

Here's a summary of the steps involved in using the enhanced Battery-run rickshaw system:

At first we used two motors for this project . To control and run the motor , we connected the motors with Motor driver (L298N) . As motor driver cant work by itself and it requires command to work , it was connected to a micro-controller circuit named Aurduino UNO R3 . Then necessary codes were given as the input of Aurduino . The Aurduino was connected to other electronic components . To control motor speed , we used the potentiometer and we used sonar HC-SR 04 to detect obstacles . This works as an automatic braking system which can detect obstacles within 20cm . The LCD display that we used has 16 pins . To reduce the pin numbers we used an extra module named I2c which converts 16 pins into 4 pins . To provide power to all the components , we used a LiPo Battery containing 12V . Remaining components (Indicator, headlamps) were powered by a solar panel which we intend to put on the hood of the rickshaw . We aimed to reduce extra energy losses .

# 7.Code

#include <LiquidCrystal_I2C.h> #include <Wire.h>

// HC-SR04 Ultrasonic Sensor pins #define trigPin 9
#define echoPin 10

// Motor A pins (Left motor) #define motorEnableA 5
#define motorIn1 6

#define motorIn2 7

// Motor B pins (Right motor) #define motorEnableB 11
#define motorIn3 8

#define motorIn4 12

// Potentiometer pin
#define potPin A0

// Distance limit to stop the motors
const int stopDistance = 20; // Adjust as needed (in cm)

// Initialize the LCD with I2C address 0x27, 16 columns, and 2 rows LiquidCrystal_I2C lcd(0x27, 16, 2);

long duration;
int distance;

void setup() {
// Initialize Serial Monitor Serial.begin(9600);

// Set up motor pins
pinMode(motorEnableA, OUTPUT); pinMode(motorIn1, OUTPUT); pinMode(motorIn2, OUTPUT);

pinMode(motorEnableB, OUTPUT); pinMode(motorIn3, OUTPUT); pinMode(motorIn4, OUTPUT);

// Set up ultrasonic sensor pins pinMode(trigPin, OUTPUT);
pinMode(echoPin, INPUT);

// Initialize the LCD
lcd.init(); // Initialize the LCD lcd.backlight(); // Turn on the LCD backlight lcd.print("Motor Speed:");
}

void loop() {
// Ultrasonic sensor reading digitalWrite(trigPin, LOW); delayMicroseconds(2);
digitalWrite(trigPin, HIGH); delayMicroseconds(10);
digitalWrite(trigPin, LOW);

duration = pulseIn(echoPin, HIGH);
distance = duration * 0.034 / 2; // Convert to cm

// Read potentiometer for speed control
int potValue = analogRead(potPin);
int motorSpeed = map(potValue, 0, 1023, 0, 178); // 70% of max speed

// Display speed on LCD
lcd.setCursor(0, 1);
lcd.print("Speed: ");
lcd.print(motorSpeed);
lcd.print(" "); // Clear extra characters if overwritten

// Motor control based on distance
if (distance >= stopDistance) {
// Run motors if no object within stop distance analogWrite(motorEnableA, motorSpeed); analogWrite(motorEnableB, motorSpeed);

// Set direction (forward)

digitalWrite(motorIn1, HIGH); digitalWrite(motorIn2, LOW); digitalWrite(motorIn3, HIGH); digitalWrite(motorIn4, LOW);
} else {
// Stop motors if object is within stop distance analogWrite(motorEnableA, 0); analogWrite(motorEnableB, 0);
}

delay(100); // Short delay for stability }

# 8.Hardware Demonstration

The figure below shows the finished HW part



Video link of prototype: https://www.youtube.com/shorts/Rr9jDDKW8tM

# 9.Problems Faced

We encountered some challenges while generating the ARDUINO code. We faced an issue with the SONAR sensor while implementing the hardware, as it failed to detect obstacles properly due to internal hardware problems. It might need multiple attempts to function correctly unless held in a specific position. Additionally, the LED we initially used did not respond properly. Initially, we suspected an issue with the solar panel. But after replacing the LCD, we confirmed that the solar panel was functioning correctly, and the problem was solely with the previous LCD.

# 10. Conclusion

In this project , we utilized the functions of a Battery-run rickshaw . This Enhanced Battery-powered rickshaw model represents a sophisticated integration of sensor technologies , digital data-monitoring systems & energy saving mechanism to ensure safety & increase efficiency. In this model , we used SONAR sensor , Solar panel , LCD ,LED , MOTOR driver and Potentiometer . Our intention to ensure safety while enhancing performance and saving energy were accomplished by the above mentioned components .This model is also beneficial for natural and economical perspectives as it reduces Carbon footprint and increases durability . As we are saving energy by using the Solar Panel ,it is also helping us not to rely heavily on power grids for electricity .
Overall , the project is a successful implementation of solar energy and sensors ensuring proper safety .

# 11. References

1. Ahmed, M. R., Das, B. K., & Tushar, M. S. H. K. (2023). Investigation of a grid-integrated hybrid energy system for residential and electric vehicle (3-wheeler) loads under schedule grid outage. Alexandria Engineering Journal, 80, 241–258. https://doi.org/10.1016/j.aej.2023.08.057
2. ENERGY CONSUMPTION BY BATTERY OPERATED AUTO-RICKSHAWS. (2013). DAFFODIL

INTERNATIONAL UNIVERSITY JOURNAL OF SCIENCE AND TECHNOLOGY, 8(2), 71.

https://www.bip.org.bd/admin/uploads/member-publication/2013/202001250931511.pdf

3. Issue-I, T. A. (2022, February 2). Impact of ban on battery-run rickshaws in districts. The Financial

Express. https://thefinancialexpress.com.bd/views/columns/impact-of-ban-on-battery-run-rickshaws-in-

districts-1643812426 (https://thefinancialexpress.com.bd/views/columns/impact-of-ban-on-battery-run-rickshaws-in-districts-1643812426)

4. https://www.tinkercad.com/things/9a0EzJVoBrF/editel?sharecode=sQkeSWPK3nWY5nMlFGdWmH7

SoYoP_1VOd5YGY4Q7PtE (https://www.tinkercad.com/things/9a0EzJVoBrF/editel)

# 12 Contributions

## a. Contribution of team member 1

## AR-RAFI ISHRAQ

## I researched on the component selection and found out the necessary components for our project with my team mate number 2,3 & 4. After fixing the component list, I went to buy the necessary components

with my team number 2,4,5 & 6 from Patuatuli , Puran Dhaka. Hardware implementations were done by all of my team members. We sat together while doing our project & got the work done together.

## Personally, I set up the components. I searched up the codes for

individual Modules and modified the code according to our project.

## While coding, at first, the codes weren’t working and then necessary debugging was done to run the code properly. . Necessary debugging in the hardware portion was also done by me & my team member

number 2.


Signature

## b. Contribution of team member 2

## ISHRAK ANAN

## I researched on the component selection and found out the necessary components for our project with my team mate number 1,3 & 4. After fixing the component list, I went to buy the necessary components

with my team number 1,4,5 & 6 from Patuatuli, Puran Dhaka. Hardware implementations were done by all of my team members. We sat together while doing our project & got the work done together.

## Personally, I contributed in wiring and soldering with my team mate number 3,4,5 & 6. Necessary debugging in the hardware portion was also done by me & my team member number 1. I made the whole

presentation slide with the help of my team member number 3.


Signature

## c. Contribution of team member 3

## TAUFEEQ HASSAN OMIO

## I researched on the component selection and found out the necessary components for our project with my team mate number 1,2 & 4. I also researched about the project feasibility and impacts of the projects

while writing the project proposals with my team mate number 4 & 6. Hardware implementations were done by all of my team members. We sat together while doing our project & got the work done together.

## Personally, I contributed in wiring and soldering with my team mate

number 2,4,5 & 6. Then I, with the help of my team mate number 4,

## wrote the whole report. I also contributed in making the presentation

slide with my team mate number 2.


Signature

## d. Contribution of team member 4

## ASHFIQ UL RAHMAN

I researched on the component selection and found out the necessary components for our project with my team mate number 1,2 & 3. After fixing the component list, I went to buy the necessary components with my team number 1,2,5 & 6 from Patuatuli, Puran Dhaka. I also researched about the project feasibility and impacts of the projects

while writing the project proposals with my team mate number 3 & 5. Hardware implementations were done by all of my team members. We sat together while doing our project & got the work done together.

## Personally, I contributed in wiring and soldering with my team mate

number 2,3,5 & 6. Then I, with the help of my team mate number 3, wrote the whole report.


Signature

## e. Contribution of team member 5

## TAHSIK ISLAM SAMPAD

After fixing the component list, I planned the necessary budget with my team mate number 6. Then I went to buy the necessary components with my team number 1,2,4 & 6 from Patuatuli, Puran Dhaka. I also researched about the project feasibility and impacts of the projects while writing the project proposals with my team mate number 3 & 4. Hardware implementations were done by all of my team members. We sat together while doing our project & got the work done together. Personally, I contributed in wiring and soldering

with my team mate number 2,3,4 & 6.


Signature

## f. Contribution of team member 6

## BAYZID MOHAMMOD SAKIB

After fixing the component list, I planned the necessary budget with my team mate number 6. Then I went to buy the necessary components with my team number 1,2,4 & 6 from Patuatuli, Puran Dhaka. Hardware implementations were done by all of my team members. We sat together while doing our project & got the work done together. Personally, I contributed in wiring and soldering with my team mate number 2,3,4 & 6. I also contributed in the

documentation part.


Signature

## 13.CO PO covered

POs | Program3 Outcomes (POs) | Tic
| Upon graduation, from the Bachelor of Science in Electrical and Electronic Engineering program, the students are expected to have the ability to:
PO1 | Engineering knowledge: Apply knowledge of mathematics, natural science, engineering fundamentals and an engineering specialization to the solution of complex electrical and electronic engineering problems. | ✓
PO2 | Problem analysis: Identify, formulate, research literature and analyse complex electrical and electronic engineering problems reaching substantiated conclusions using first principles of mathematics, natural sciences and engineering sciences. | ✓
PO3 | Design/development of solutions: Design solutions for complex electrical and electronic engineering problems and design systems, components or processes that meet specified needs with appropriate consideration for public health and safety, cultural, societal, and environmental considerations. | ✓
PO4 | Investigation: Conduct investigations of complex electrical and electronic engineering problems using research-based knowledge and research methods including design of experiments, analysis and interpretation of data, and synthesis of information to provide valid conclusions. | ✓
PO5 | Modern tool usage: Create, select and apply appropriate techniques, resources, and modern engineering and IT tools, including prediction and modelling, to complex electrical and electronic engineering problems, with an understanding of the limitations. | ✓
PO6 | The engineer and society: Apply reasoning informed by contextual knowledge to assess societal, health, safety, legal and cultural issues and the consequent responsibilities relevant to professional engineering practice and solutions to complex electrical and electronic engineering problems. | ✓
PO7 | Environment and sustainability: Understand and evaluate the sustainability and impact of professional engineering work in the solution of complex electrical and electronic engineering problems in societal and environmental contexts. | ✓
PO8 | Ethics: Apply ethical principles embedded with religious values, professional ethics and responsibilities, and norms of electrical and electronic engineering practice.
PO9 | Individual work and teamwork: Function effectively as an individual, and as a member or leader in diverse teams and in multi-disciplinary settings. | ✓
PO10 | Communication: Communicate effectively on complex engineering activities with the engineering community and with society at large, such as being able to comprehend and write effective reports and design documentation, make effective presentations, and give and receive clear instructions. | ✓
PO11 | Project management and finance: Demonstrate knowledge and understanding of engineering management principles and economic decision-making and apply these to one’s own work, as a member and leader in a team, to manage projects and in multidisciplinary environments. | ✓
PO12 | Life-long learning: Recognize the need for, and have the preparation and ability to engage in independent and life-long learning in the context of electrical and electronic engineering related technological change. | ✓

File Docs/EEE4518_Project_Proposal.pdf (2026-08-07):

## PROJECT PROPOSAL

## ENHANCEMENT OF BATTERY-POWERED RICKSHAWS

BY

## TEAM MURUBBEEE

## TEAM MURUBBEEE

## 1. Ar-Rafi Ishraq – 210021330 2. Ishrak Anan - 210021212 3. Taufeeq Hassan Omio - 210021214 4. Ashfiq Ul Rahman - 210021342 5. Tahsik Islam Sampad - 210021318

Overview:

We, team Murubbeee, aim to work on enhancing battery-run rickshaws in Bangladesh. Battery rickshaws have become a common urban transportation in Bangladesh, especially in busy cities like Dhaka, and Chittagong. According to Dhaka Tribune’s report on May 24, 2024, almost 60 lakh battery rickshaws are operating on the streets of Bangladesh. These rickshaws provide us with the benefits of fast transportation as compared to their counterpart, human-powered rickshaws. However, these benefits come with a price. Battery rickshaws are the major reasons for accidents, excessive electricity usage, and traffic-related issues. To address these issues and also upgrade these battery-run rickshaws for more efficient results, we propose our newly modified battery rickshaws.

Problem Statement:

Battery-run rickshaws are the cause of a good number of problems in the urban areas of our country. The major issues that we will be addressing are:

1. Unnecessary speeding of battery rickshaws.
2. Collisions that lead to minor or severe injuries and life threats
3. Excessive use of electricity for charging the battery-run rickshaws
4. Lack of safety measurements in the rickshaws
5. Absence of an information system in the rickshaw.

Battery-run rickshaws are most criticized for their poor safety measurements and functionality. The major issue is that these rickshaws do not have any safety options to control overspeeding. The speeds these rickshaws can gain are often too hard to control with the brakes they are equipped with. These lead to collisions with other vehicles on the road and serious injuries, sometimes even death. The inclusion of speed sensors and automatic response systems for overspeeding can resolve this issue to an extent.

Another problem that the battery-run rickshaws create is the electricity they consume for charging. A study conducted in 2023 shows that the battery-run rickshaws consume up to 450 MW of electricity every day. However, this number might be even larger as there are many illegal connections used for charging these rickshaws. To address this issue, the use of renewable energy systems and the addition of a hybrid mechanism is proposed.

Outline of the proposed solution:

To solve the mentioned problem statements above, we aim to use several sensors and a hybrid mechanism in battery-run rickshaws accompanied by the use of renewable sources to cater to power saving. The proposed modifications are:

1. Solar panel installation on the top of rickshaw hoods
2. Speed sensors to detect the speed of the rickshaw
3. Obstacle detector to be installed at the front portion
4. A system that can respond to overspeed and reduce chances of collisions by controlling the power supply to motor.
5. A reverse charging facility that can use the rotation of wheels to charge the battery
6. Addition of indicator lamps and headlamps
7. Information system (LED display) to show necessary data (speed, charge, etc.)

The prototype we aim to make will comprise of the following modules:

- Arduino
- Solar panel
- Speed measuring module
- Ultrasonic SONAR sensor (HC-SR04)
- Dual Motor drivers
- LCD module
- LED
- An alternator


Project timeline:


References:

1. Ahmed, M. R., Das, B. K., & Tushar, M. S. H. K. (2023). Investigation of a gridintegrated hybrid energy system for residential and electric vehicle (3-wheeler) loads under schedule grid outage. Alexandria Engineering Journal, 80, 241–258. https://doi.org/10.1016/j.aej.2023.08.057
2. ENERGY CONSUMPTION BY BATTERY OPERATED AUTO-RICKSHAWS.

(2013). DAFFODIL INTERNATIONAL UNIVERSITY JOURNAL OF SCIENCE AND

TECHNOLOGY, 8(2), 71. https://www.bip.org.bd/admin/uploads/member-

publication/2013/202001250931511.pdf

3. Issue-I, T. A. (2022, February 2). Impact of ban on battery-run rickshaws in districts. The

Financial Express. https://thefinancialexpress.com.bd/views/columns/impact-of-ban-on-

battery-run-rickshaws-in-districts-1643812426

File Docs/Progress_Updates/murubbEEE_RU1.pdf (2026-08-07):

# PROJECT REPORT


### TEAM NAME: MurubbEEE

### TEAM MEMBERS

### 1. Ar-Rafi Ishraq – 210021330 2. Ishrak Anan - 210021212 3. Taufeeq Hassan Omio - 210021214 4. Ashfiq Ul Rahman - 210021342 5. Tahsik Islam Sampad – 210021318

### 6.Bayzid Mohammod Sakib-210021250

### PROJECT: ENHANCEMENT OF A BATTERY POWERED RICKSHAW

We, Team MurubbEEE aimed to design a battery powered rickshaw in which there will be some features like: speed control of motor, obstacle detector (automatic breaking), indicator lamps and headlamps using solar panel. Using Fritzing , We have formulated a circuit where we have used potentiometer ,sonar sensor ,LED,solar panel ,motors , aurduino UNO and motor drivers . Features that have been processed so far:

- Speed Control :
-For speed controlling , we have used potentiometer. Potentiometer is actually a variable resistor , by varying resistance we can control current which will also control the acceleration .
- Obstacle Detection :
-For obstacle detection , we have used sonar sensor(HC SR-04) .
- Solar-Powered Indicators and Headlights:
-We want solar panel to provide required power to the indicator and headlights .( All of them will be LED)

Code ,Circuit Design & Implementation

-Using Aurduino ,we have developed a code for operating the internal circuit efficiently .
We have also implemented a circuit circuit also which is given below : | Sl.
No . | Components | Sl. No. | Components
1 Aurduino – | UNO R3 | 5 | 11V LiPo Battery
2 Motor driver- | L298N | 6 | Motors
3 Potentiometer | (10K or 50K) | 7 | Solar panel
4 Sonar sensor- | HC SR-04 | 8 | LED’s

### Primarily selected components

Circuit Design & Implementation

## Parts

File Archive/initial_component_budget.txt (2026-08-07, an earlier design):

Sonar sensor HC SR-04 : 150 TK
L298N H-Bridge Dual Motor driver: 200 TK
16*2 Serial LCD Module Display(With LCD adapter module) : 350 TK
solar panel: 350
Moto: 300*2 

LEDs
jumperwire male-to-male and male-female 
potentiometer 10k or 50k or 100k
lipo
multimeter

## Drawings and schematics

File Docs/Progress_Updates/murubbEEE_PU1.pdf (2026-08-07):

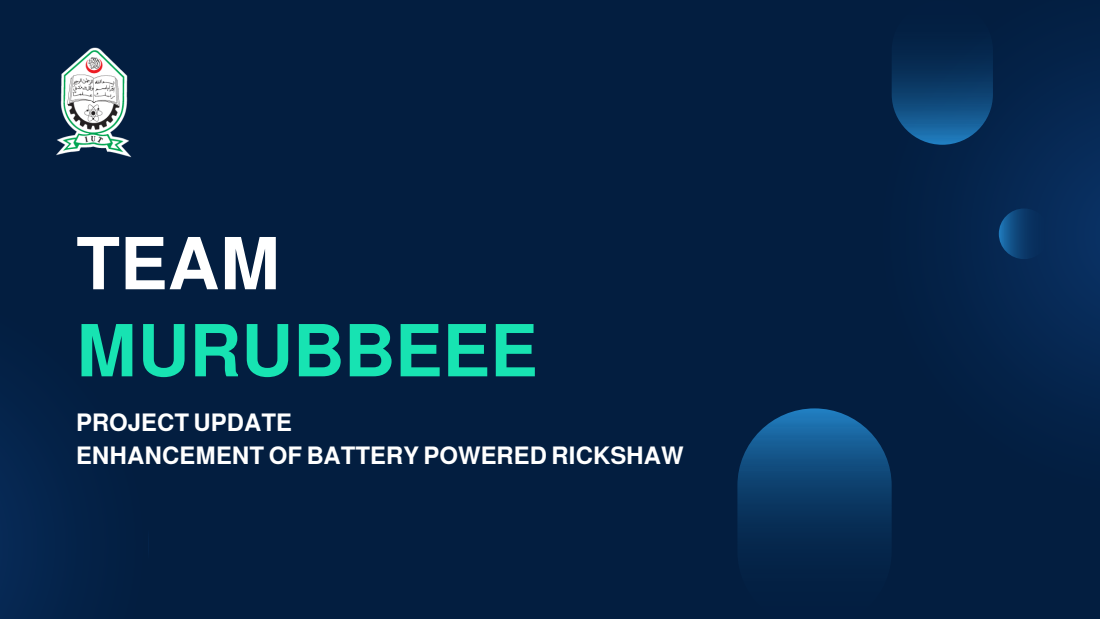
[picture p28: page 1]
TEAM MURUBBEEE

PROJECT UPDATE
ENHANCEMENT OF BATTERY POWERED RICKSHAW

## PROJECT UPDATES

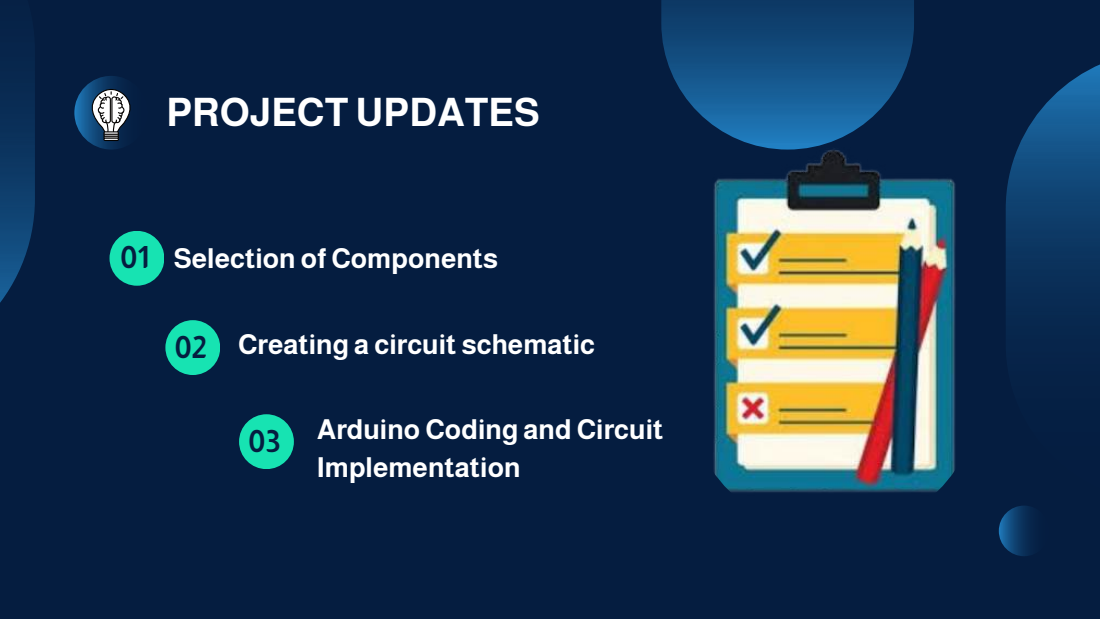
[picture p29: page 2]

Selection of Components

Creating a circuit schematic

Arduino Coding and Circuit
Implementation

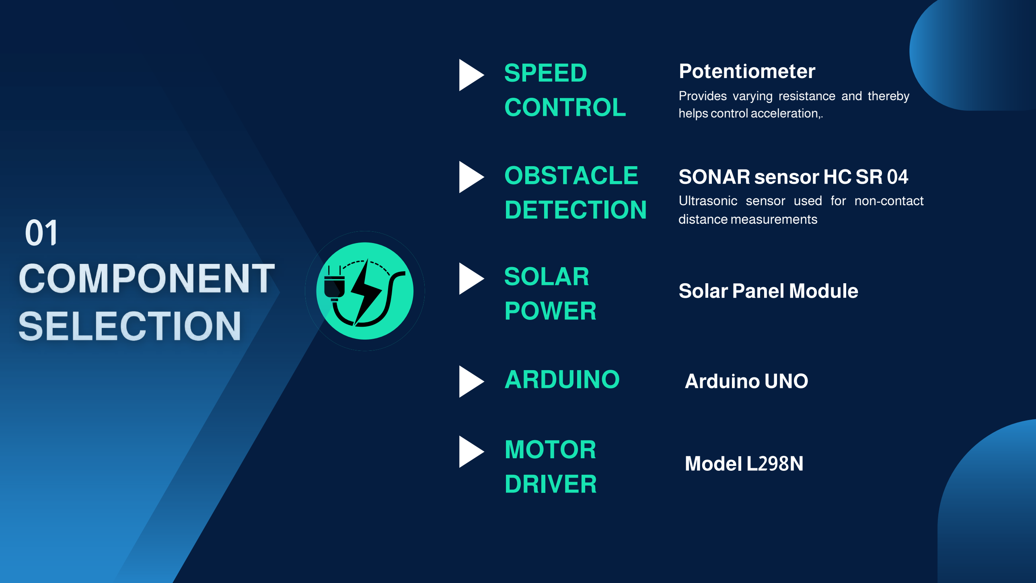
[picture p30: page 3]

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
ol a

c

c

ele

r

a

tio

n,. OBSTACLE DETECTION SPEED CONTROL SOLAR POWER ARDUINO SONAR sensor

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
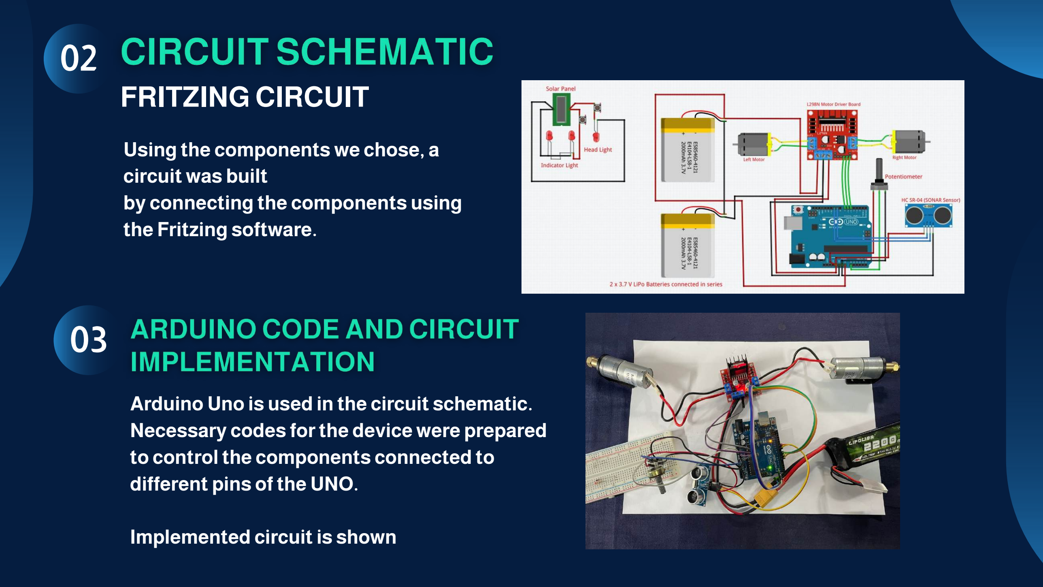
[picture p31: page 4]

### FRITZING CIRCUIT

Using the components we chose, a circuit was built
by connecting the components using the Fritzing software.

03

Arduino Uno is used in the circuit schematic. Necessary codes forthe device were prepared to controlthe components connected to different pins ofthe UNO.

Implemented circuitis shown

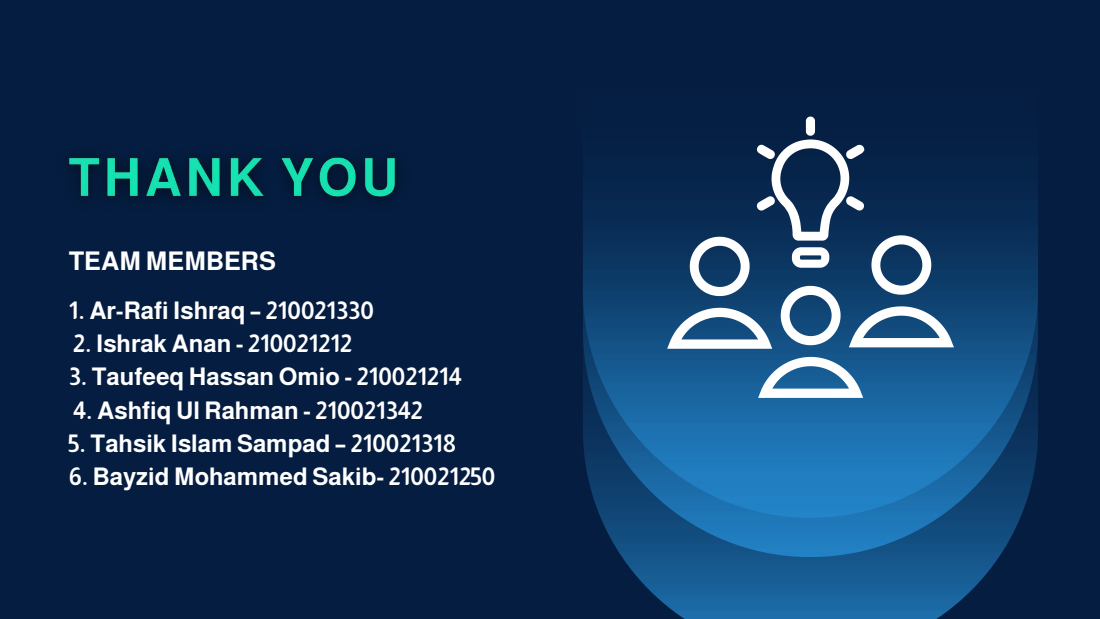
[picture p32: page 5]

TEAM MEMBERS
1. Ar-Rafi Ishraq – 210021330
2. Ishrak Anan - 210021212
3. Taufeeq Hassan Omio - 210021214
4. Ashfiq Ul Rahman - 210021342
5. Tahsik Islam Sampad – 210021318
6. Bayzid Mohammed Sakib- 210021250

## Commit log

2026-08-07 Arduino Source Code
2026-08-07 Total Circuit Schematic of the Prototype
    [l298n-arduino.fzz]
